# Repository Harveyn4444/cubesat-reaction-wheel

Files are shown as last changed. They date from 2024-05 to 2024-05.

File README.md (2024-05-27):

# The Design of a 1U CubeSat and Related Controllers
<p align="center">
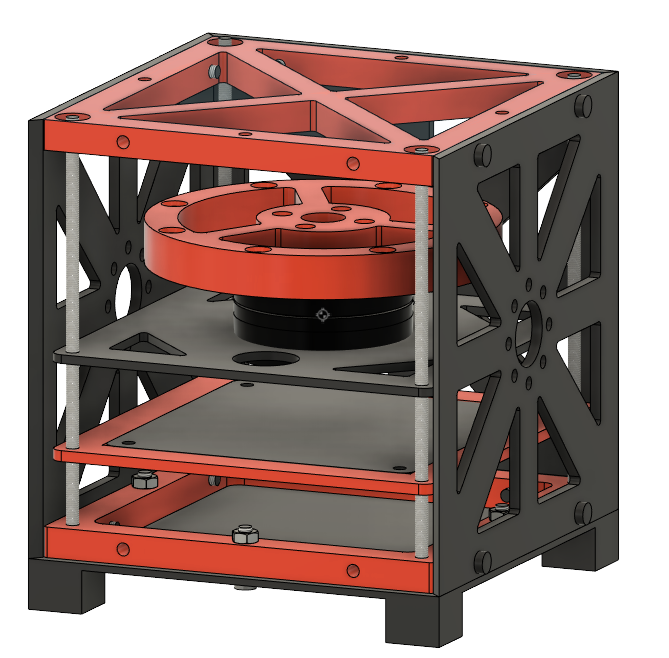
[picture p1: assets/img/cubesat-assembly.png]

</p>

The goal of the project was to create a CubeSat Reaction Wheel contained within 1U primarily using COTS components and open source solutions.

##  [Hardware](https://github.com/Harveyn4444/cubesat-reaction-wheel/tree/main/hardware) 
The hardware section is a combination of 3D printer files, PCB schematics and production files.

The structure was custom made and can be reproduced using the stl files provided with recommended slicer parameters. 

The custom PCB can be assembled with the production files and the Bill of Materials provided.

## [Code](https://github.com/Harveyn4444/cubesat-reaction-wheel/tree/main/code)

### Arduino / Microcontroller
Example test code for the sensors used and example code to control the BLDC motor.

### Plotting
Code included to read and log serial data output and save this data and plot it.

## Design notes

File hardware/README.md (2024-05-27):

# Hardware

The hardware section is a combination of 3D printer files, PCB schematics and production files.

The structure was custom made and can be reproduced using the stl files provided with recommended slicer parameters.

The custom PCB can be assembled with the production files and the Bill of Materials provided.

## [Structure](https://github.com/Harveyn4444/cubesat-reaction-wheel/tree/main/hardware/structure)

### STL files
These files are used to 3D print the model. You will need slicer software to create the files that the printer can use. Some examples are CURA(Most printers) and Prusaslice (For Prusa printers like I used).

### .f3d files
These files are used to export the model into fusion360 to modify. 

## [PCB](https://github.com/Harveyn4444/cubesat-reaction-wheel/tree/main/hardware/pcb)
A custom PCB was created to contain the electronics and sensors for the CubeSat. This keeps everything neat and tidy and makes testing and operation much easier.

### Gerber files
Gerber files are used to produce the actual PCBs. To design the schematics and PCBs I used [EasyEDA](https://easyeda.com/) where you can export the gerber files for production. To manufacture the PCBs I used [JLCPCB](https://jlcpcb.com/), which provide a high quality product at a very low cost (Use the cheapest shipping method that takes 2 weeks!). 

## [Bill of Materials](https://github.com/Harveyn4444/cubesat-reaction-wheel/tree/main/hardware/bom)
A BOM is included as not everything can be 3D printed. The exta hardware used will include links but anything similar shoudl work (Plus links could expire).

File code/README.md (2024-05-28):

# Code

A collection of cude to use the hardware, and to log the sensor data written to the serial terminal by the micro controller. This was used as a reliable effective method top obtain data during testing. During operation data would be written to the SD card or Flash chip if required. The flash chip was used as the rotation may force the SD Card to come loose and the flash chip provides a more robust solution.

## [Testing](https://github.com/Harveyn4444/cubesat-reaction-wheel/tree/main/code/testing)
Code used by the Teensy to read data from sensors and communicate with the SimpleFOCShield.

## [Data Logging](https://github.com/Harveyn4444/cubesat-reaction-wheel/tree/main/code/data-logging)
The code reads the serial port the microcontroller is connected to (shown in Arduino IDE) and stores this data in a CSV file. This data/csv file is stored in the data directory and is called again within the scripts. This is to keep the data organised and seperated form the main scripts. The CSV files are manually renamed/adjusted to reflect the parameters of the code in which it is recording.

The python scripts make use of a virtual python enviroment and requires requirements.txt to be installed. The venv is local to each users own machine. Useful guides/documentation can be found at:

```
https://docs.python.org/3/library/venv.html
https://packaging.python.org/en/latest/guides/installing-using-pip-and-virtual-environments/
https://www.freecodecamp.org/news/how-to-setup-virtual-environments-in-python/
```

```
serial-to-csv.py
```
Reads the serial port created by the microcontroller and logs this data to the CSV file for plotting later. To end the process in the terminal press cntrl + C. serial-to-csv-torque.py performs the same tasks just saves the data as different files and was used seperately to keep things tidy.

```
plot.py
```
Plots a single graph and saves the figure under the name of the CSV file as an image. The same is for plot-alpha.py, this was just to plot the angular acceleration graphs.

```
multiple-plot.py
```
Plots multiple bits of data on one graph, used to show the change in filtering of the data by changing the RC value.

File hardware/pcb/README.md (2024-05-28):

# PCB
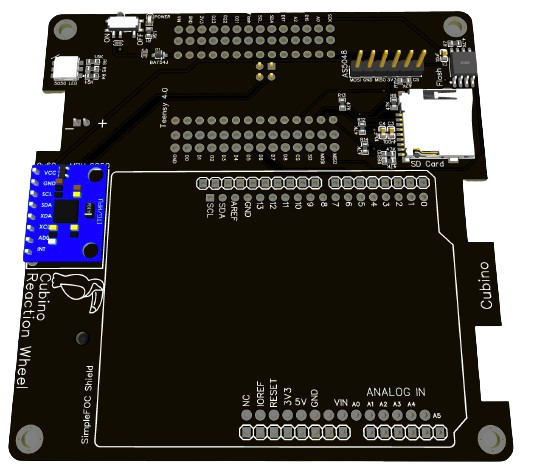
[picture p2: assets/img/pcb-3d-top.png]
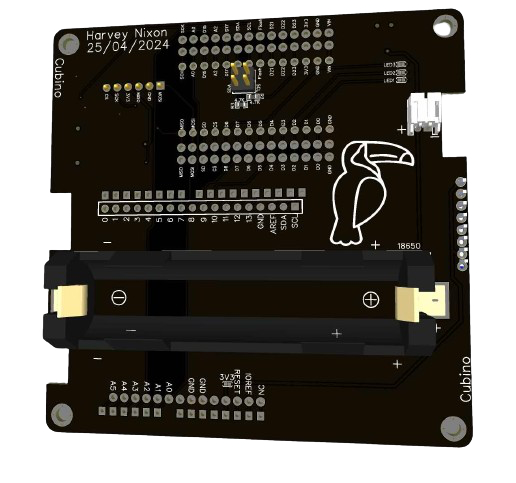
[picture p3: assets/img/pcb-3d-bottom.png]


<br clear="both"/>

A custom PCB was created to contain the vital sensors and ICs for the project.

The gerber file is the production file for the PCB. Once assembled the example code can be applied to test the use of the individual sensors and SimpleFOCShield.

### Images

<p>
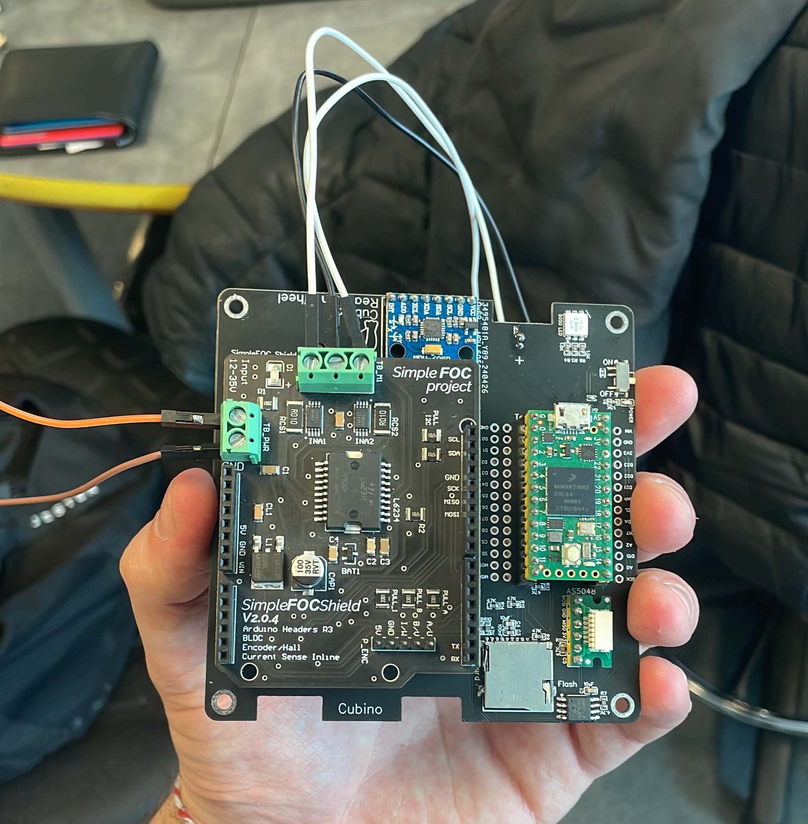
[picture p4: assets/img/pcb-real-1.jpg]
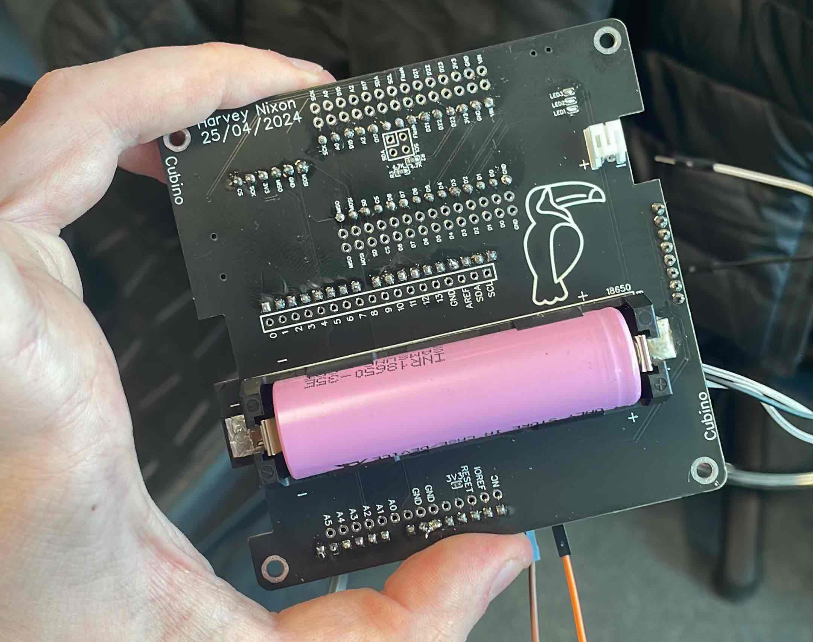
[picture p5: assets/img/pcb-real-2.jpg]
     
    <br clear="both"/>
    <p>
     
            <br clear="both"/>
        <p>
     

</p>

<br clear="both"/>

# Schematic
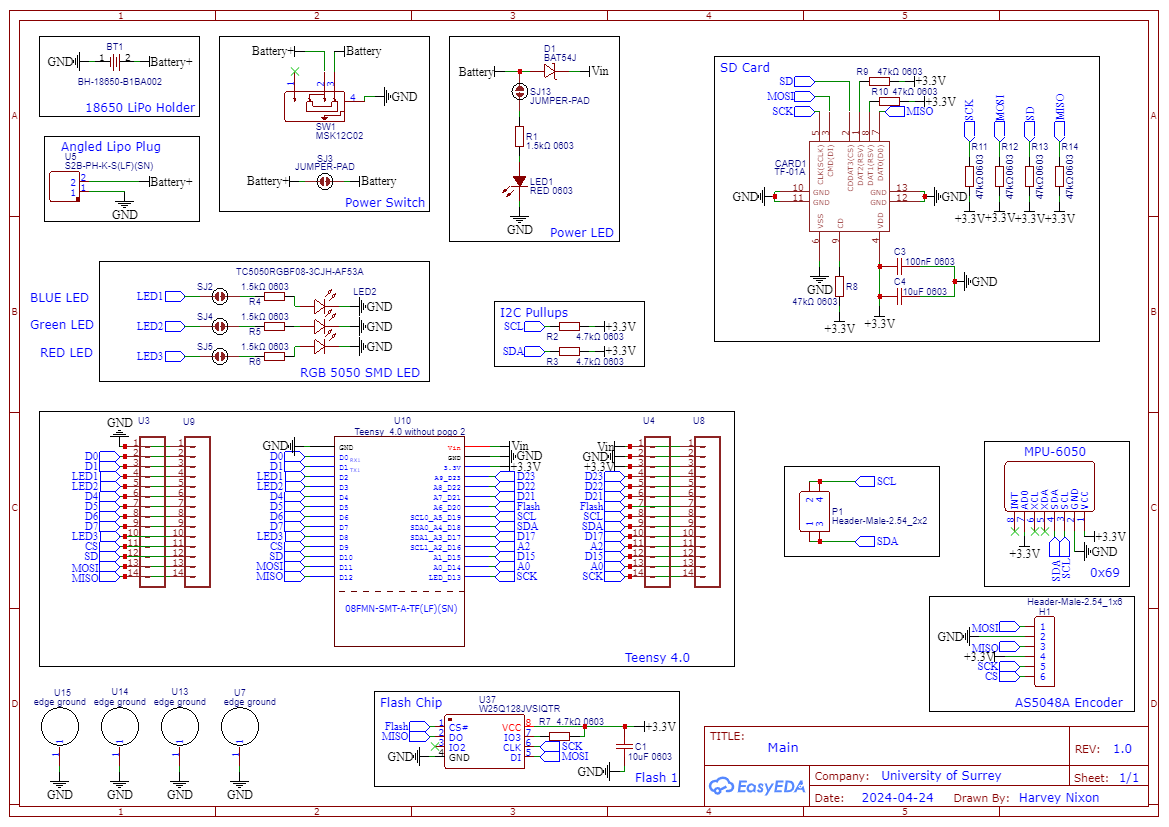
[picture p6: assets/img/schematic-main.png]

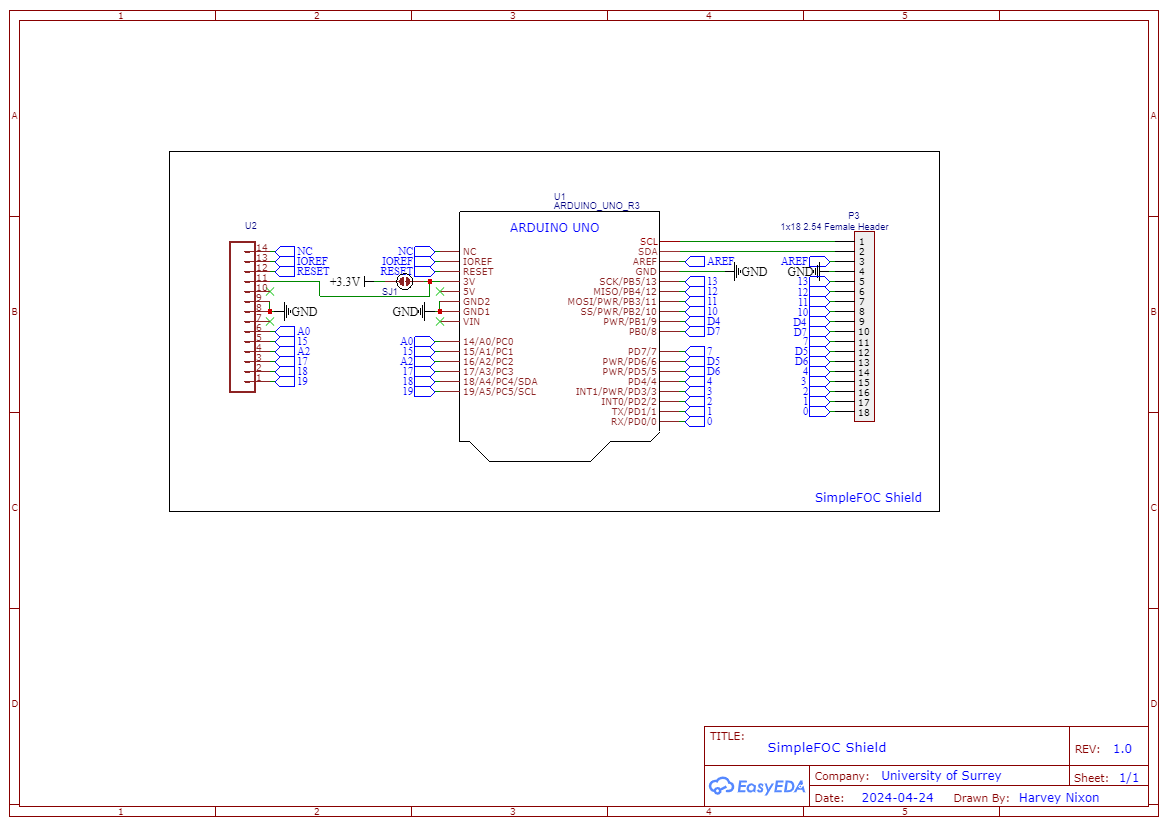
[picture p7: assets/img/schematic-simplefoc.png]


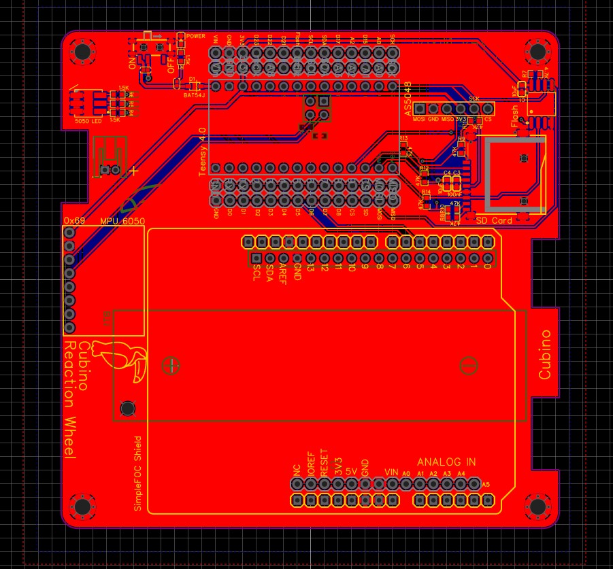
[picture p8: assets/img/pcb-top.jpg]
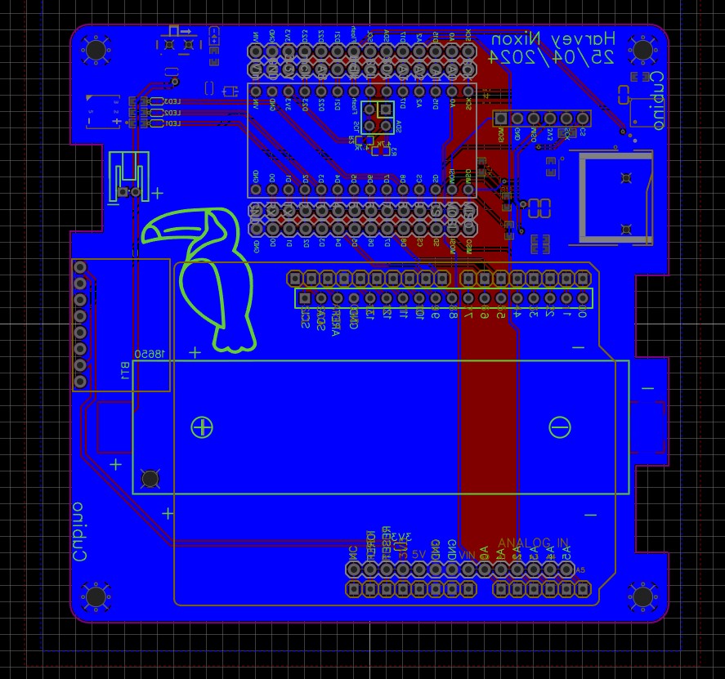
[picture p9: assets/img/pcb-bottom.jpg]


<br clear="both"/>

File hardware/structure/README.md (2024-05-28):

# CubeSat Structure

### Base

<p align="center">
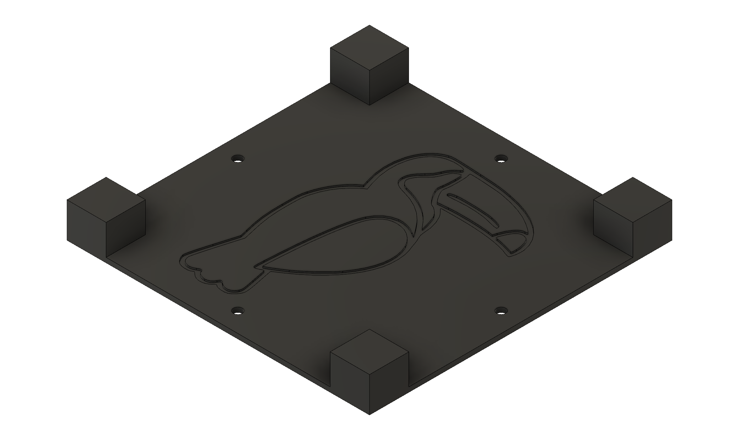
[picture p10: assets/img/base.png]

</p>

```
STL File: base.stl
Nozzle: 0.2mm
Nozzle Temperature: 215 C / 419 F
Bed Temperature: 60 C / 140 F
Infill: 30%
Filament used: 23 g
Print Time: 1h30m * Using Prusa mini+ default speeds and settings
```

### Base Holder

<p align="center">
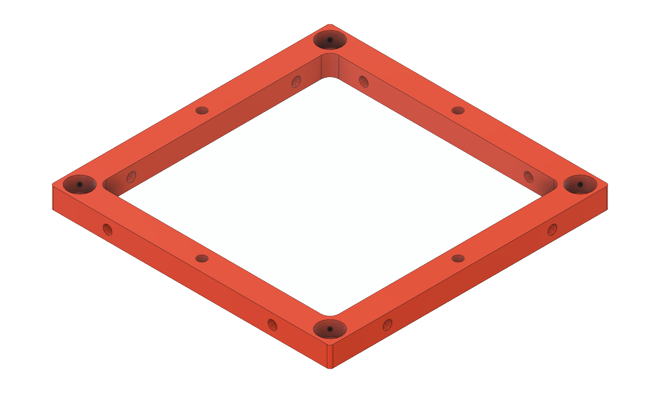
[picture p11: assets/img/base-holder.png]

</p>

```
STL File: base-holder.stl
Nozzle: 0.2mm
Nozzle Temperature: 215 C / 419 F
Bed Temperature: 60 C / 140 F
Infill: 30%
Filament used: 16 g
Print Time: 1h22m * Using Prusa mini+ default speeds and settings
```

### Top Holder

<p align="center">
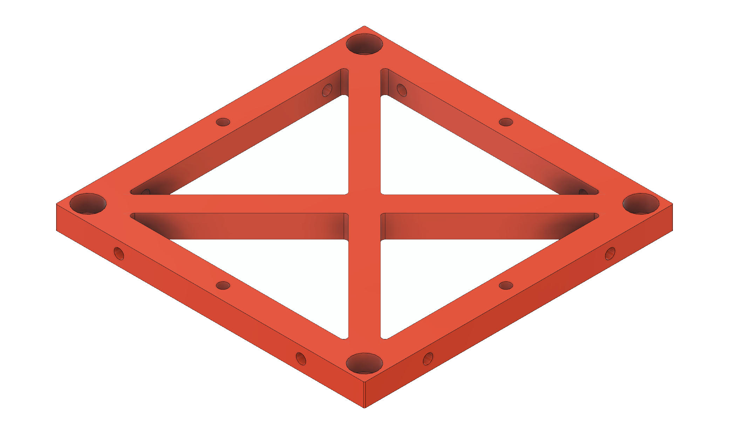
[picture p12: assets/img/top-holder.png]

</p>

```
STL File: top-holder.stl
Nozzle: 0.2mm
Nozzle Temperature: 215 C / 419 F
Bed Temperature: 60 C / 140 F
Infill: 30%
Filament used: 24 g
Print Time: 1h58m * Using Prusa mini+ default speeds and settings
```

### Top

<p align="center">
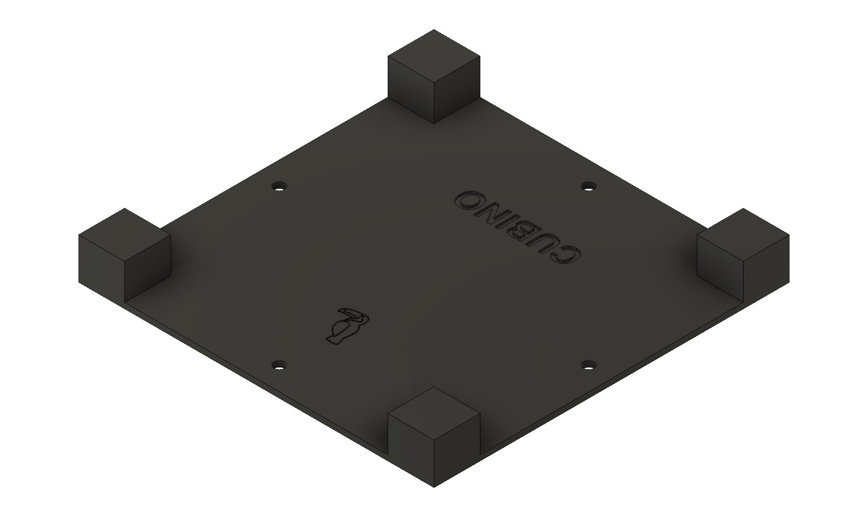
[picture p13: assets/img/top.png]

</p>

```
STL File: top.stl
Nozzle: 0.2mm
Nozzle Temperature: 215 C / 419 F
Bed Temperature: 60 C / 140 F
Infill: 30%
Filament used: 25g
Print Time: 1h27m * Using Prusa mini+ default speeds and settings
```

### Wall

<p align="center">
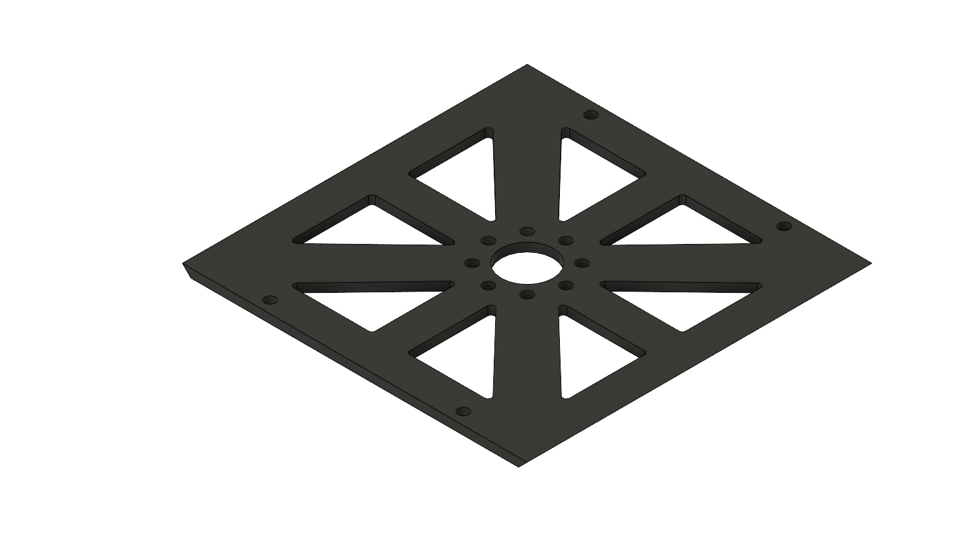
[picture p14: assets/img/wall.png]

</p>

```
STL File: wall.stl
Nozzle: 0.2mm
Nozzle Temperature: 215 C / 419 F
Bed Temperature: 60 C / 140 F
Infill: 30%
Filament used: 20g
Print Time: 1h21m *Using Prusa mini+ default speeds and settings **Each wall
```
The walls have a 45 degree angle desgined in to ensure flush fitment, print with the chamfer facing upwards.

<p align="center">
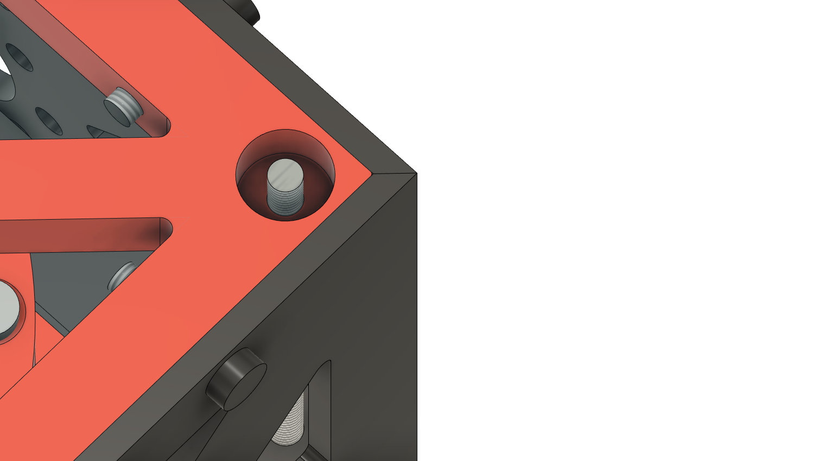
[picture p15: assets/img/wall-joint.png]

</p>

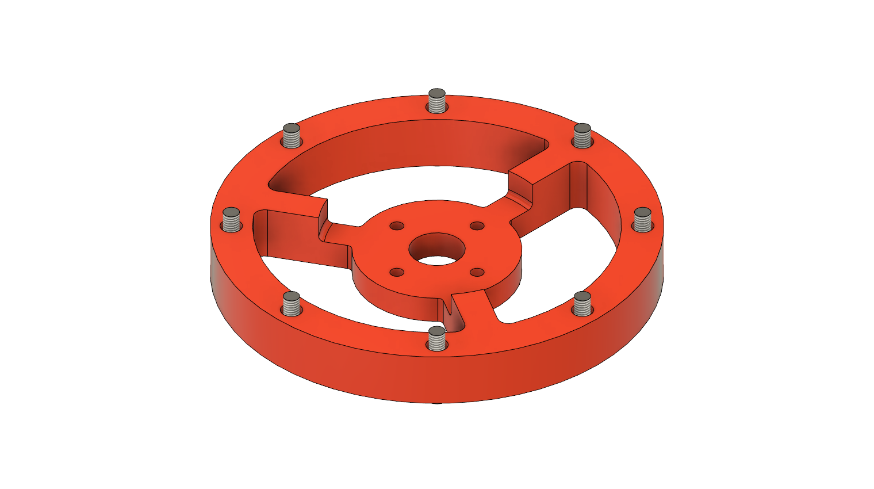
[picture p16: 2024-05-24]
assets/img/wheel-screws.png

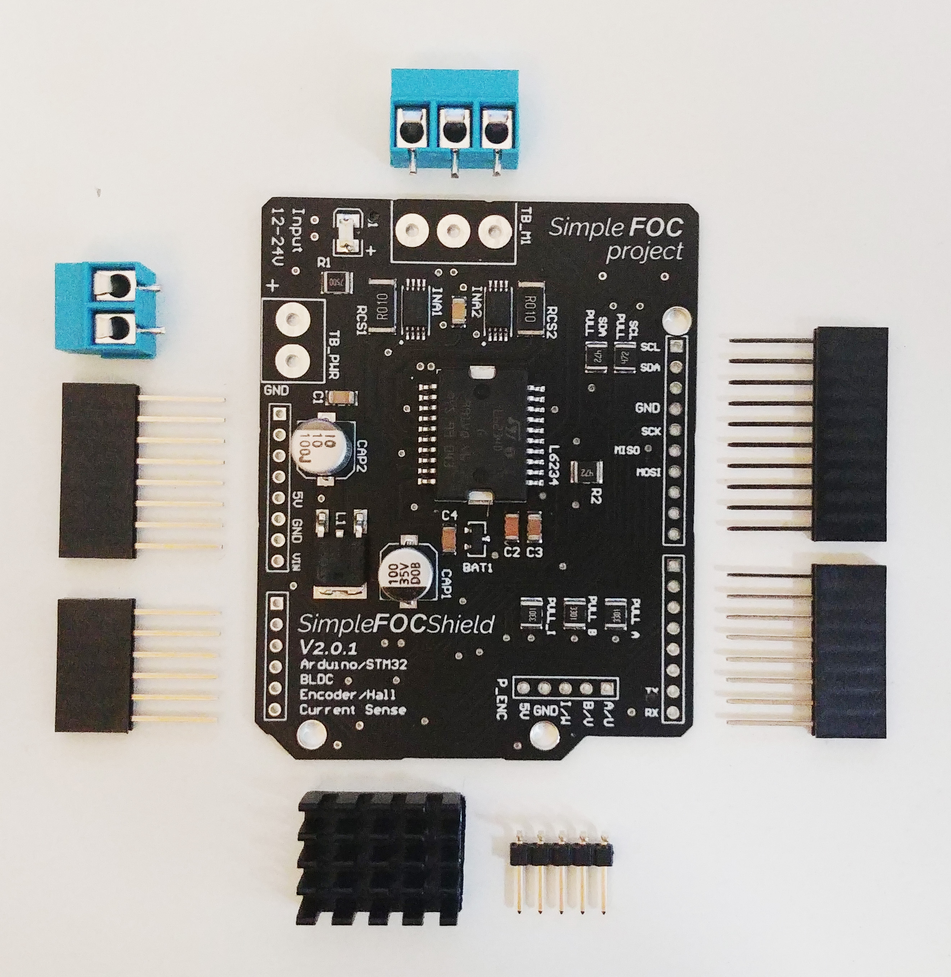
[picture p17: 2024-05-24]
assets/img/simple-foc-shield.jpg

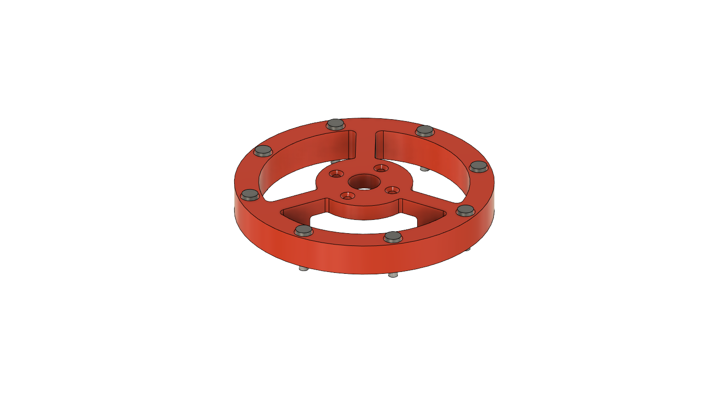
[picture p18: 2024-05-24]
assets/img/wheel-top.png

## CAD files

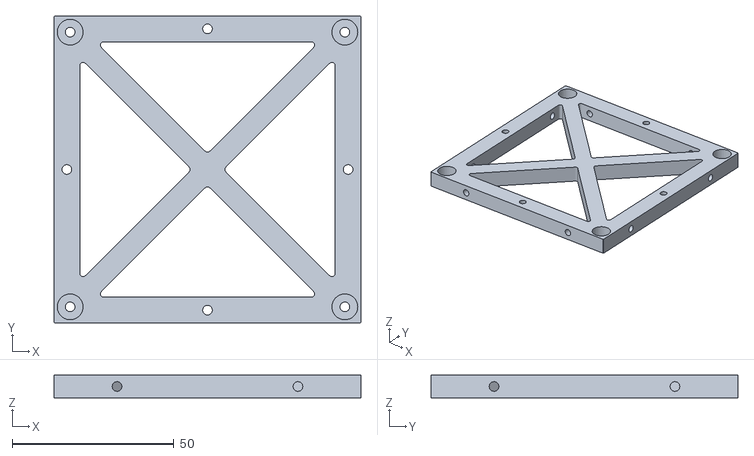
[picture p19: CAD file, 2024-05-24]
hardware/structure/top-holder.stl
95.0 x 95.0 x 7.00

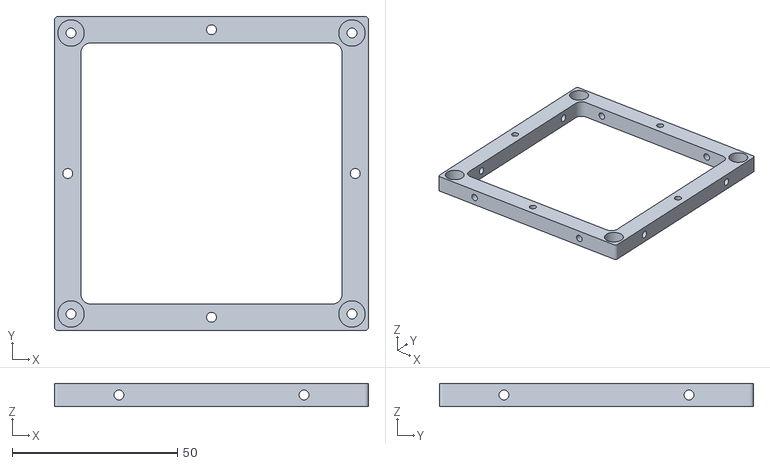
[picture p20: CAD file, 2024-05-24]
hardware/structure/base-holder.stl
95.0 x 95.0 x 7.00

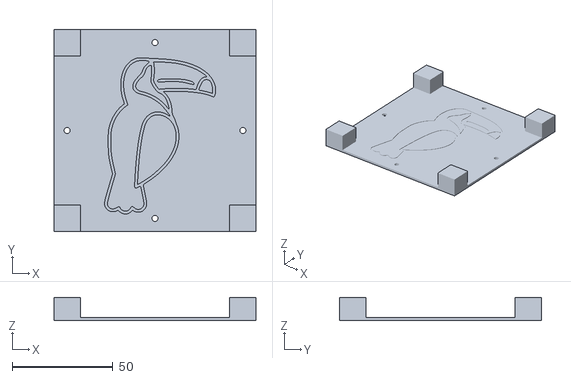
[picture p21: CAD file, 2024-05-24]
hardware/structure/base.stl
100.0 x 100.0 x 11.6

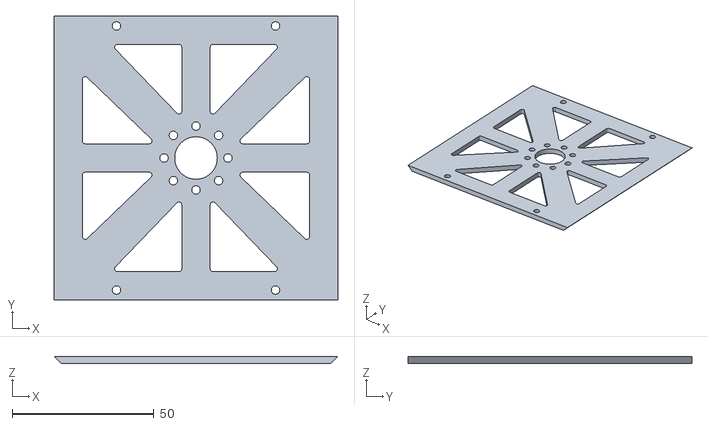
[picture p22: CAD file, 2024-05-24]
hardware/structure/wall.stl
100.0 x 100.0 x 2.50

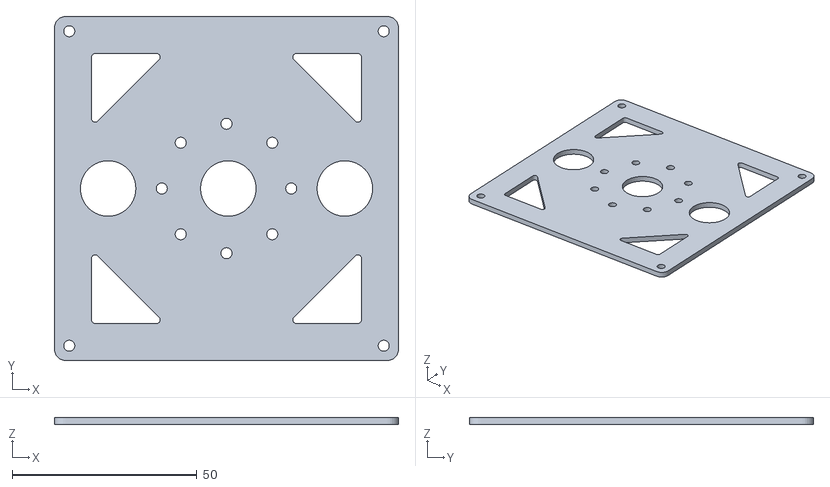
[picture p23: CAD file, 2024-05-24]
hardware/structure/motor-holder.stl
93.0 x 93.0 x 2.00

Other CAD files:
hardware/structure/top.stl
hardware/structure/base-holder.f3d
hardware/structure/base.f3d
hardware/structure/motor-holder.f3d
hardware/structure/top-holder.f3d
hardware/structure/top.f3d
hardware/structure/wall.f3d

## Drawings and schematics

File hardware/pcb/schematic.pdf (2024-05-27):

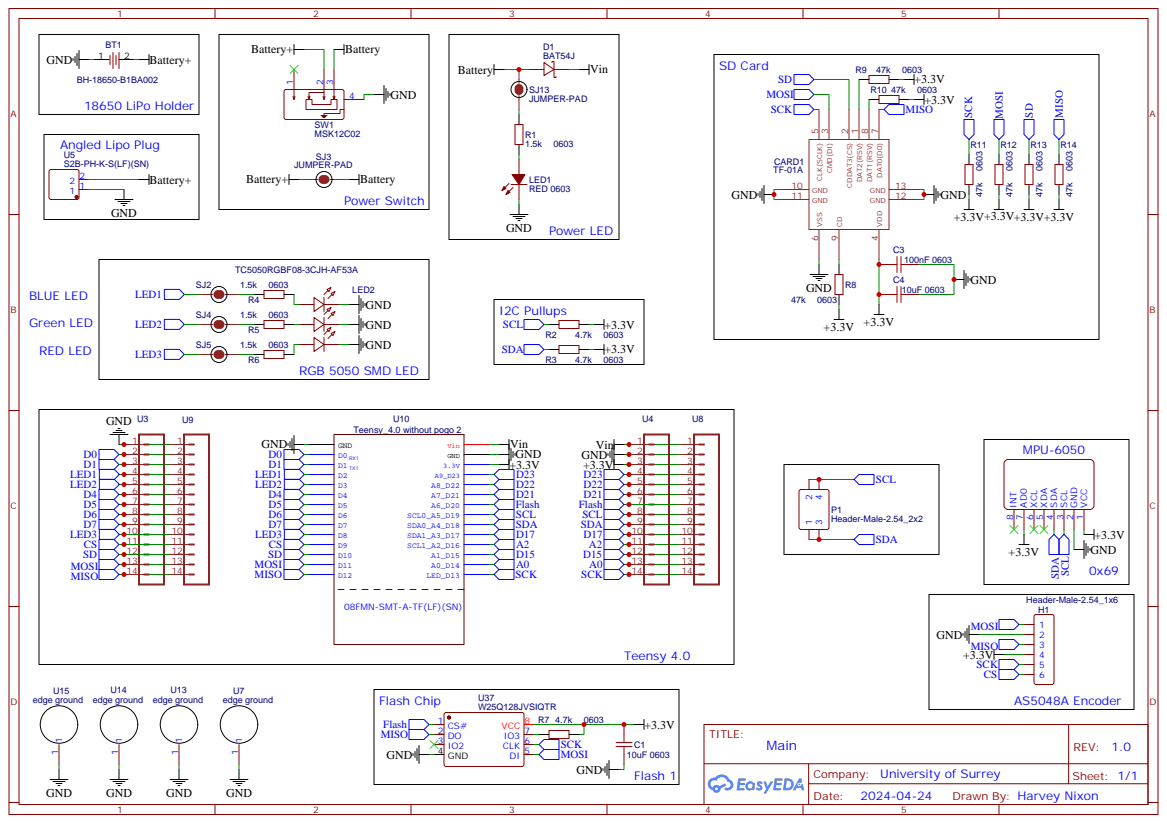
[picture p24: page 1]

08FMN-SMT-A-TF(LF)(SN)

Company: University of Surrey

Drawn By: Harvey Nixon

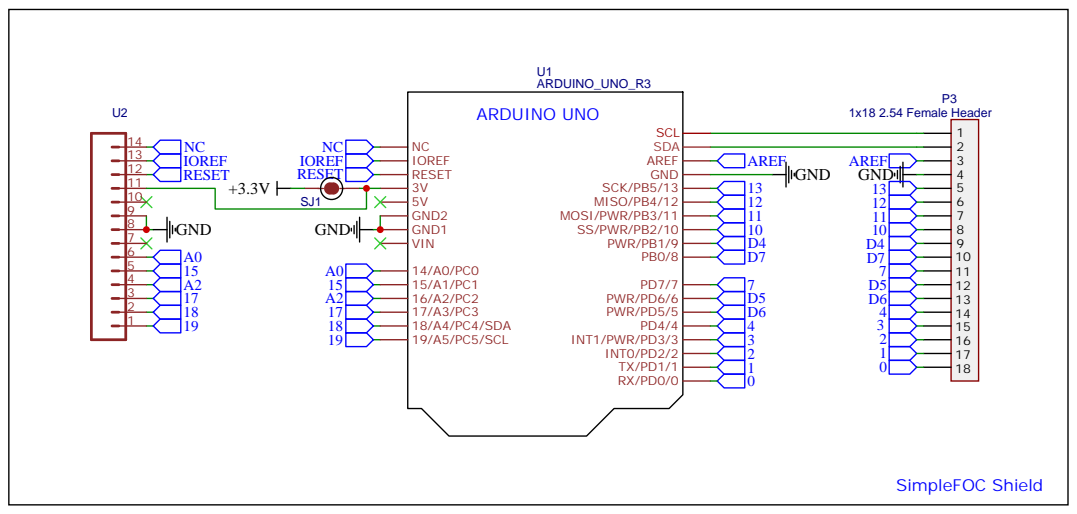
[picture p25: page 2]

Company: University of Surrey

Drawn By: Harvey Nixon

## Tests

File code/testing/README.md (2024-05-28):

# Code
## Arduino IDE
To be abvle to upload code to the Teensy 4.0, the board manager is needed to be installed. In arduino preferences add the link below to the preferences box and then under board manager you will be able install the Teensy board manager *Note this is only avaliable with an internet connection. 

```
https://www.pjrc.com/teensy/package_teensy_index.json
```
The Arduino IDE used was version 2.3.2.
The Arduino IDE can be downloaded [here](https://www.arduino.cc/en/software).

<p align="center">
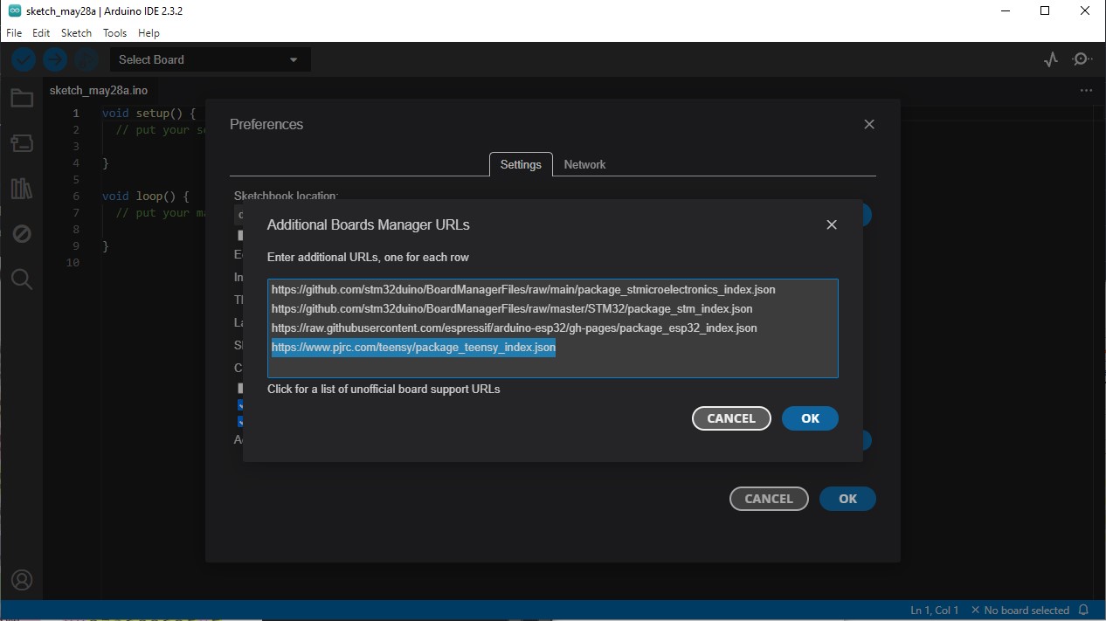
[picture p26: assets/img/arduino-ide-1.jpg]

</p>
<p align="center">
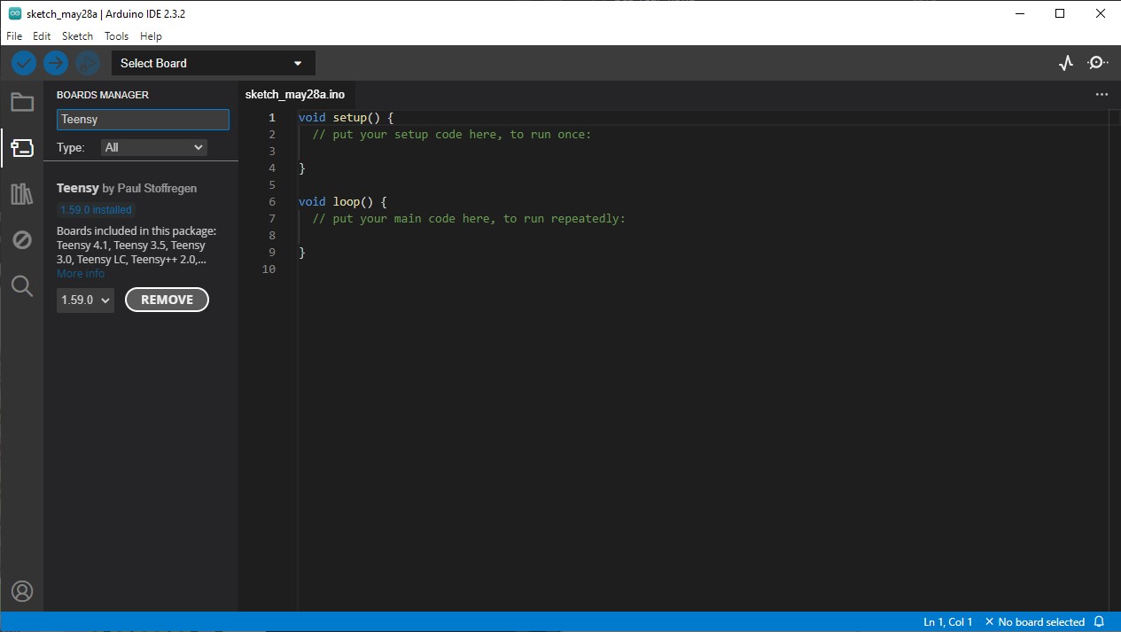
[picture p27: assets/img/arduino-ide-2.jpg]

</p>
<p align="center">
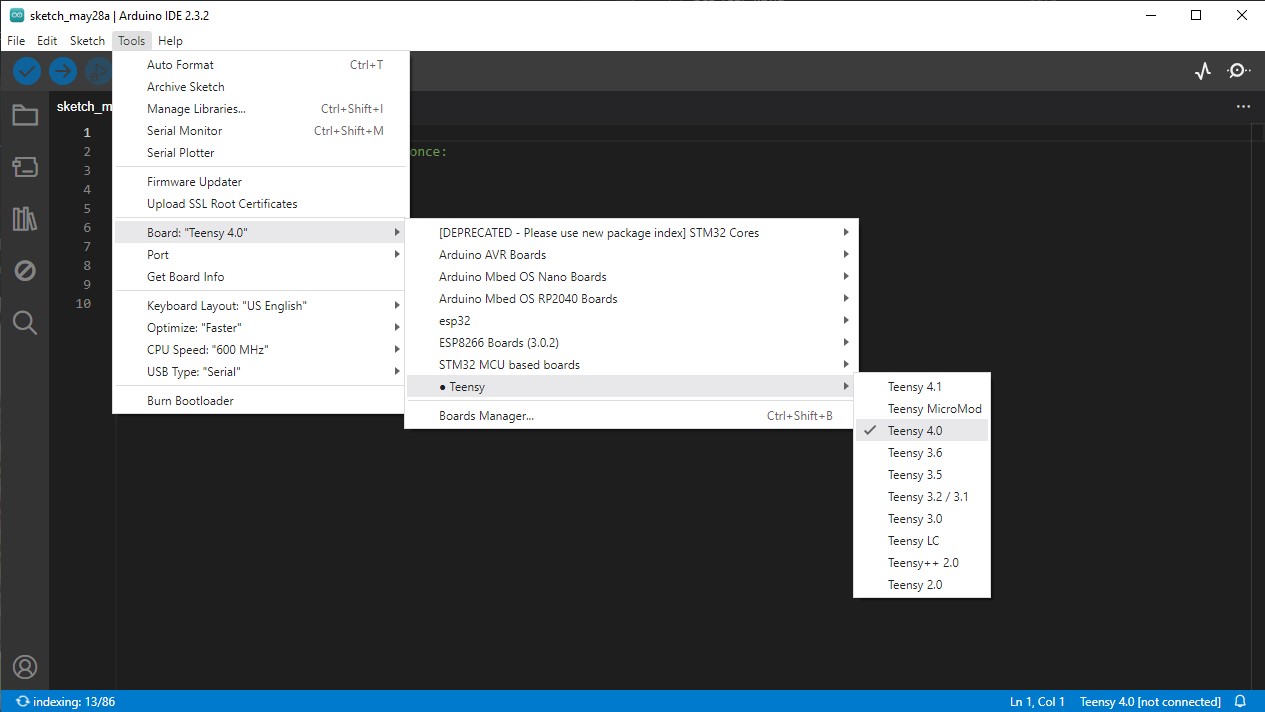
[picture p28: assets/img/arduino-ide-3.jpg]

</p>

## Microcontroller 
The final microcontroller used was the Teensy 4.0 which provides amazing performance for the price point of ~£24.
Information about the Teensy 4.0 can be found on the webiste [here](https://www.pjrc.com/store/teensy40.html)

<p align="center">
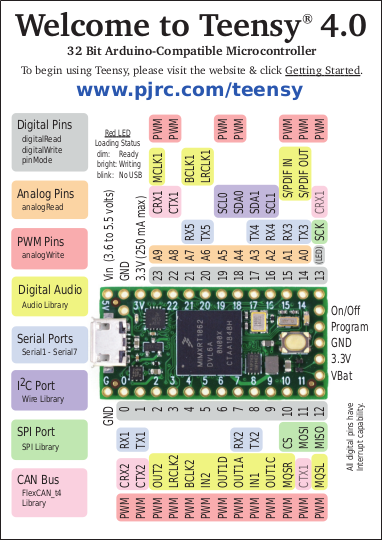
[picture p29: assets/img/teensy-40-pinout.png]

</p>

## Libraries

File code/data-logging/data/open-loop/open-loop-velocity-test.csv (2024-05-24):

Number | Target | Measured | Error
0 | 20.00 | 0.00 | 20.00
1 | 20.00 | 2.58 | 17.42
2 | 20.00 | 5.53 | 14.47
3 | 20.00 | 6.63 | 13.37
4 | 20.00 | 7.00 | 13.00
5 | 20.00 | 9.21 | 10.79
6 | 20.00 | 9.21 | 10.79
7 | 20.00 | 7.00 | 13.00
8 | 20.00 | 2.95 | 17.05
9 | 20.00 | -2.21 | 22.21
10 | 20.00 | -8.10 | 28.10
11 | 20.00 | -13.26 | 33.26
12 | 20.00 | -19.52 | 39.52
13 | 20.00 | -23.21 | 43.21
14 | 20.00 | -23.58 | 43.58
15 | 20.00 | -26.16 | 46.16
16 | 20.00 | -19.89 | 39.89
17 | 20.00 | -15.10 | 35.10
18 | 20.00 | -6.26 | 26.26
19 | 20.00 | -1.10 | 21.10
20 | 20.00 | 4.42 | 15.58
21 | 20.00 | 10.31 | 9.69
22 | 20.00 | 14.00 | 6.00
23 | 20.00 | 17.31 | 2.69
24 | 20.00 | 22.84 | -2.84
25 | 20.00 | 25.42 | -5.42
26 | 20.00 | 31.68 | -11.68
27 | 20.00 | 30.58 | -10.58
28 | 20.00 | 40.15 | -20.15
29 | 20.00 | 41.26 | -21.26
30 | 20.00 | 47.89 | -27.89
31 | 20.00 | 54.52 | -34.52
32 | 20.00 | 49.73 | -29.73
33 | 20.00 | 51.57 | -31.57
34 | 20.00 | 42.73 | -22.73
35 | 20.00 | 40.52 | -20.52
36 | 20.00 | 35.73 | -15.73
37 | 20.00 | 35.00 | -15.00
38 | 20.00 | 23.58 | -3.58
39 | 20.00 | 22.47 | -2.47
40 | 20.00 | 16.21 | 3.79
41 | 20.00 | 10.31 | 9.69
42 | 20.00 | 5.16 | 14.84
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

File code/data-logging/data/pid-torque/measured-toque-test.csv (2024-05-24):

Time | TargetVelocity | TargetTorque | Measured | Error | alpha | torque
0 | 20.00 | 0.1899 | -0.00 | 20.00 | -0.0008 | -0.0001
1 | 20.00 | 0.1899 | -0.04 | 20.04 | -0.0088 | -0.0009
2 | 20.00 | 0.1899 | -0.07 | 20.07 | -0.0079 | -0.0008
3 | 20.00 | 0.1899 | -0.06 | 20.06 | 0.0017 | 0.0002
4 | 20.00 | 0.1899 | 0.12 | 19.88 | 0.0460 | 0.0046
5 | 20.00 | 0.1899 | 0.32 | 19.68 | 0.0502 | 0.0050
6 | 20.00 | 0.1899 | 0.40 | 19.60 | 0.0186 | 0.0019
7 | 20.00 | 0.1899 | 0.61 | 19.39 | 0.0522 | 0.0052
8 | 20.00 | 0.1899 | 0.86 | 19.14 | 0.0648 | 0.0065
9 | 20.00 | 0.1899 | 1.03 | 18.97 | 0.0405 | 0.0041
11 | 20.00 | 0.1899 | 1.35 | 18.65 | 0.0809 | 0.0081
12 | 20.00 | 0.1899 | 1.57 | 18.43 | 0.0550 | 0.0055
13 | 20.00 | 0.1899 | 1.87 | 18.13 | 0.0762 | 0.0076
14 | 20.00 | 0.1899 | 2.08 | 17.92 | 0.0508 | 0.0051
15 | 20.00 | 0.1899 | 2.44 | 17.56 | 0.0902 | 0.0090
16 | 20.00 | 0.1899 | 2.62 | 17.38 | 0.0455 | 0.0045
17 | 20.00 | 0.1899 | 2.96 | 17.04 | 0.0854 | 0.0085
18 | 20.00 | 0.1899 | 3.16 | 16.84 | 0.0502 | 0.0050
19 | 20.00 | 0.1899 | 3.49 | 16.51 | 0.0807 | 0.0081
20 | 20.00 | 0.1899 | 3.74 | 16.26 | 0.0638 | 0.0064
21 | 20.00 | 0.1899 | 4.08 | 15.92 | 0.0840 | 0.0084
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

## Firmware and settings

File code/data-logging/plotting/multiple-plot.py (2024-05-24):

import pandas as pd
from matplotlib import pyplot as plt
from matplotlib.ticker import (MultipleLocator, AutoMinorLocator)

plt.rcParams["figure.figsize"] = [10.00, 5]
#plt.rcParams["figure.figsize"] = [25, 10.0]
plt.rcParams["figure.autolayout"] = True
#cols = ['Desired','Measured','RecordNumber']
#df = pd.read_csv("Code/LoggingData/PIDVelocity1.csv",skiprows=[2], nrows=1000, usecols=cols) #
cols = ['Time','Target','Measured', 'Error']
df1 = pd.read_csv("Code\LoggingData\Data\OpenLoopRC\OpenLoopVelocityFiltered01.csv",skiprows=[1], nrows=100, usecols=cols) #
df3 = pd.read_csv("Code\LoggingData\Data\OpenLoopRC\OpenLoopVelocityFiltered03.csv",skiprows=[1], nrows=100, usecols=cols)
df5 = pd.read_csv("Code\LoggingData\Data\OpenLoopRC\OpenLoopVelocityFiltered05.csv",skiprows=[1], nrows=100, usecols=cols)
df7 = pd.read_csv("Code\LoggingData\Data\OpenLoopRC\OpenLoopVelocityFiltered07.csv",skiprows=[1], nrows=100, usecols=cols)

#print("Contents in csv file:", df)
print("Contents in csv file:")
print(df1)
Time1 = df1['Time']
Target1 = df1['Target']
Measured1 = df1['Measured']
Time3 = df3['Time']
Target3 = df3['Target']
Measured3 = df3['Measured']
Time5 = df5['Time']
Target5 = df5['Target']
Measured5 = df5['Measured']

Time7 = df7['Time']
Target7 = df7['Target']
Measured7 = df7['Measured']



plt.rcParams['toolbar'] = 'None' # Remove tool bar (upper bar)
plt.figure('  | Individual Project | CubeSat Reaction Wheel | Open Loop Velocity Test')#,facecolor='black')
#plt.axhline(y=0.5, color='r', linestyle='-')
plt.plot(Time1, Target1, color = 'red')
plt.plot(Time1, Measured1, color = 'black')#, color = 'white')
plt.plot(Time3, Measured3)#, color = 'white')
plt.plot(Time5, Measured5)#, color = 'white')
plt.plot(Time7, Measured7)#, color = 'white')
#plt.plot(RecordNumber, df.Measures)
#plt.plot(df.RecordNumber, df.Measures)
#df.plot(figsize=(15,5), kind='line',x=2, y=1)
#df.plot(figsize=(15,5), kind='line',x=df.RecordNumber, y=df.Desired)


ax = plt.gca()
#fig, ax = plt.plot( facecolor='black') #Share the same x axis - e.g. time


#plt.xlabel("Time")
#plt.ylabel("Temperature / 0c")


plt.xlabel("Time / ms")
plt.ylabel("Angular Velocity / Rads-1")
plt.legend(['Target Velocity', 'RC = 0.1', 'RC = 0.3', 'RC = 0.5','RC = 0.7'])

ax.set_ylim([-30, 60])
ax.set_title('Target Velocity') 
ax.tick_params(axis='x')
ax.xaxis.set_major_locator(MultipleLocator(10))
ax.set_xlim(xmin=0)


""" ax.set_title('Temperature', color = 'white')
ax.xaxis.label.set_color('white')
ax.tick_params(axis='x', colors='white')
ax.yaxis.set_major_locator(MultipleLocator(10))
ax.yaxis.set_major_formatter('{x:.0f}')
ax.tick_params(axis='y', colors='white')

ax.set_facecolor('black')

ax.spines['bottom'].set_color('#FF3E00AA')
ax.spines['top'].set_color('#FF3E00AA')
ax.spines['right'].set_color('#FF3E00AA')
ax.spines['left'].set_color('#FF3E00AA')
 """
#plt.figure.canvas.manager.set_window_title('  |Peryton Space | Weather Balloon Project | Data Dashboard Freezer Test')
#plt.figure.tight_layout()

plt.savefig('Code/LoggingData/Data/TestingRC.png', dpi = 400)

#mng = plt.get_current_fig_manager()
#mng.window.state('zoomed') 
#mng.window.wm_iconbitmap("Avionics\Freezer Test\Data\Logo.ico")
plt.show()

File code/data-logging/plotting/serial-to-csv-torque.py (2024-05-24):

import serial

arduino_port = "/dev/tty.usbmodem106736801" #serial port of Arduino
baud = 115200 #arduino uno runs at 9600 ba
#fileName="analog-data.csv" #name of the CSV file generated
#fileName="Code/LoggingData/Data/PIDTestx.csv" #name of the CSV file generated
fileName="Code/LoggingData/Data/PIDTorque/MeasuredTorqueTEST2.csv" #name of the CSV file generated

ser = serial.Serial(arduino_port, baud)
print("Connected to Arduino port:" + arduino_port)
file = open(fileName, "a")
#file.write("P 2.5, I 20, D 0, Tf 0.01, ramp 300" + "\n")
file.write("Time,TargetVelocity,TargetTorque,Measured,Error,alpha,torque" + "\n")
samples = 1000000 #how many samples to collect
print_labels = False
line = 0 #start at 0 because our header is 0 (not real data)
while line <= samples:
    # incoming = ser.read(9999)
    # if len(incoming) > 0:
    if print_labels:
        if line==0:
            print("Printing Column Headers")
        else:
            print("Line " + str(line) + ": writing...")
    getData=ser.readline()
    data=getData[0:][:-2]
    data = getData.decode('utf-8').strip('\r\n')
    print(data)

    file = open(fileName, "a")
    file.write(data + "\n") #write data with a newline
    line = line+1

print("Data collection complete!")
file.close()
